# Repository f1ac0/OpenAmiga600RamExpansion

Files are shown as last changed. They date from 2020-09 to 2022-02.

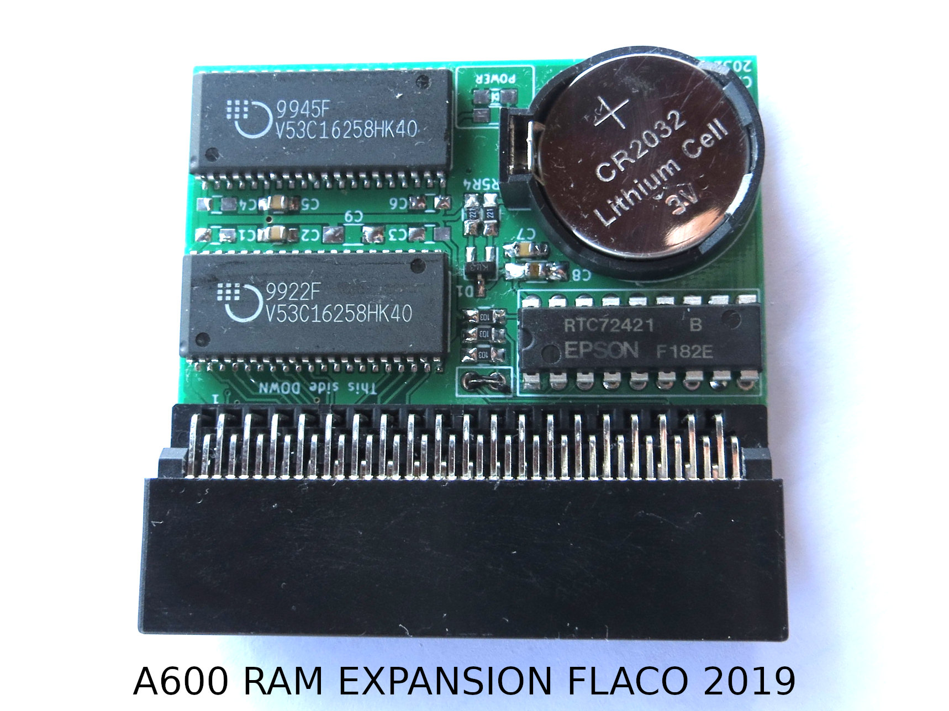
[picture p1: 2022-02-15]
OpenAmiga600RamExpansion FLACO 2019.JPG

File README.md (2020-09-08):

# OpenAmiga600RamExpansion
OpenAmiga600RamExpansion is an Open Hardware 1 MB Chip RAM Expansion for the Commodore Amiga 600 Computer with optional Real Time Clock, by SukkoPera https://github.com/SukkoPera/OpenAmiga600RamExpansion/.

This project is a different layout of the board, with almost the same BOM :
- smaller board, no space for ram chips sockets,
- inverted connector, so that components are facing downside and the solder joints do not touch the trapdoor,
- footprint for CR1220 in addition to the CR2032.

# Disclaimer
This is a hobbyist project, it comes with no warranty and no support.

This version is not connected to SukkoPera, please don't bother him with issues you might have because of it.

I publish this work using the same license as the original project : CERN OHL v1.2.

If you find it useful, please reward the original author. See the original repository.

# Making it
You should refer to the original repository where SukkoPera provides excellent advice about connector availability, RAM chips to use (I personally installed V53C16256HK40) and RTC. I confirm that AmigaTestKit is a must to check that the board is working fine (among other test).

Check for shorts at least between 5V and GND traces before applying power !

# Using it
- Install the battery,
- Plug to the motherboard,
- Power on the system.

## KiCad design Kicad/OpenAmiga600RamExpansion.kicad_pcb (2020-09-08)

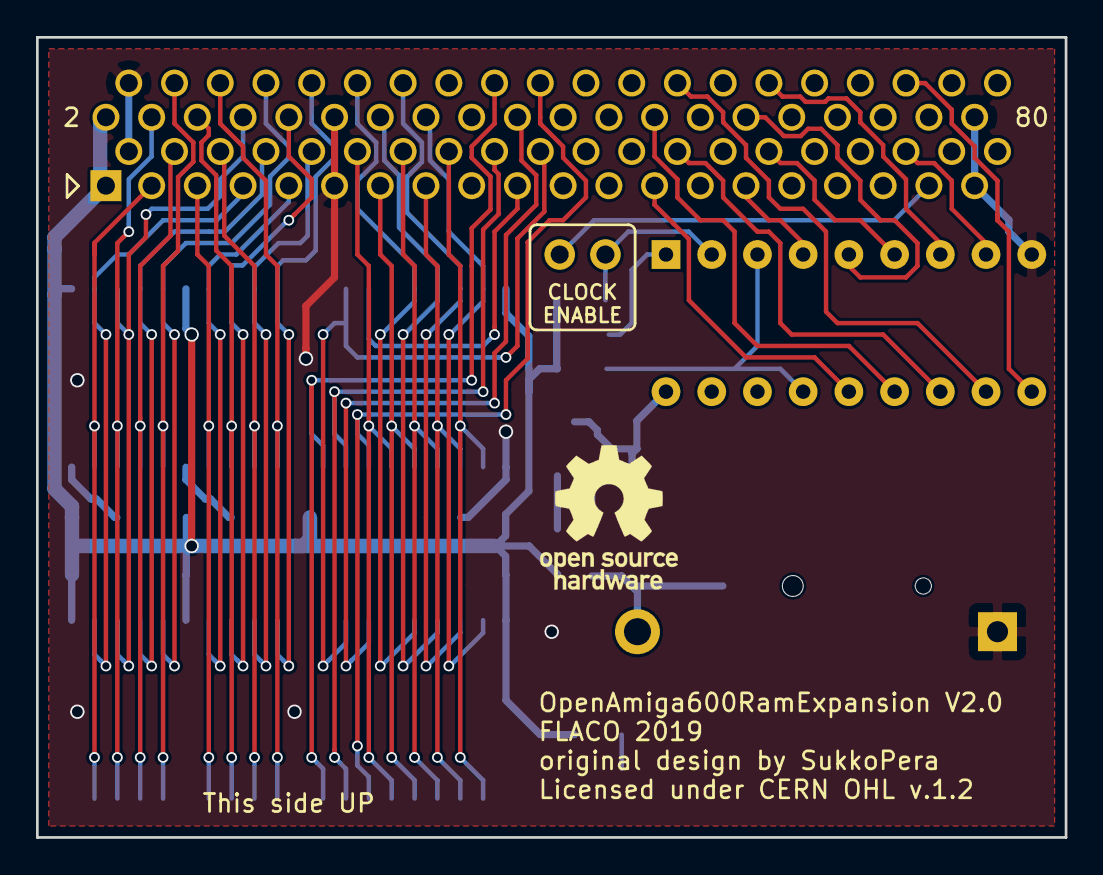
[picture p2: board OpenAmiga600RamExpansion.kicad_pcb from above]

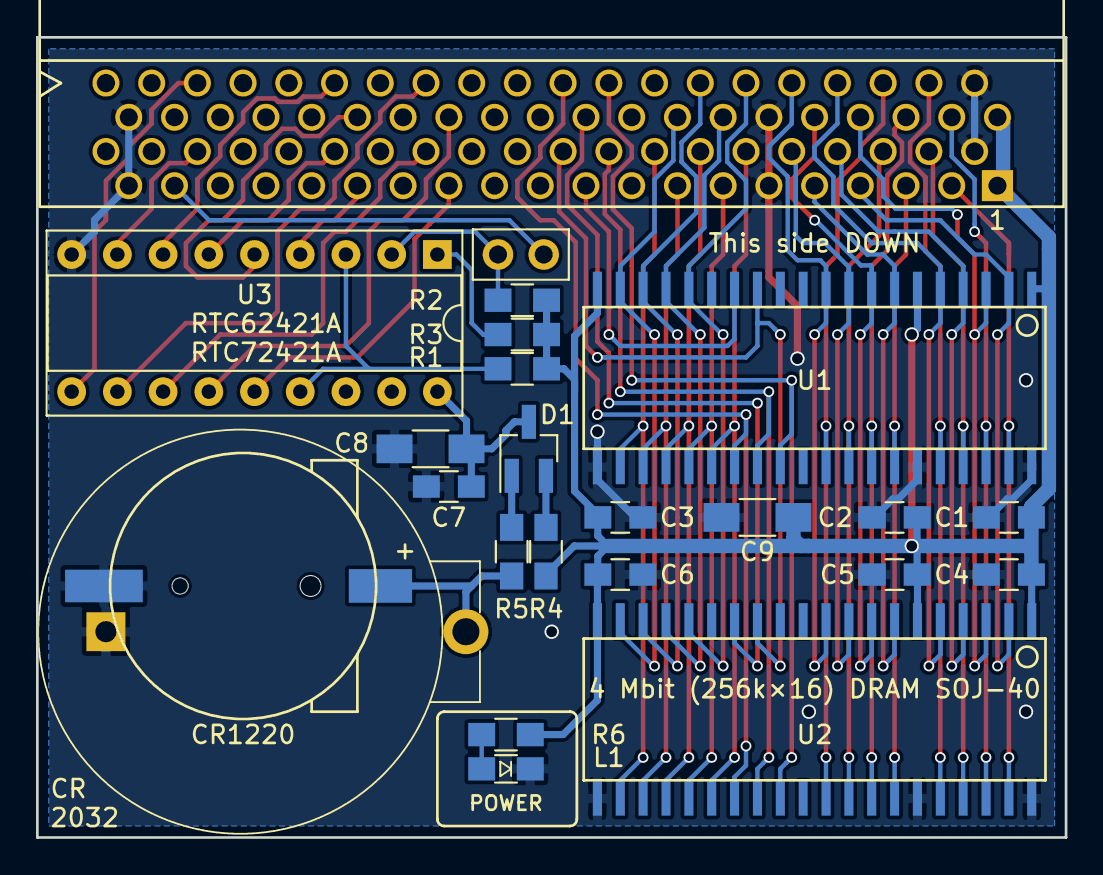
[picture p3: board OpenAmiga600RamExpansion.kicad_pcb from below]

Board: 2 copper layers, 57.2 x 44.4 mm, 25 parts (24 on the bottom side), 52 nets.

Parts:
BT1: CR2032; Battery_Holder_Coin_2032_BS-7
BT2: CR1220; Battery_Holder_Coin_1220_BS-1220-1
C1, C2, C3, C4, C5, C6, C7: 100n; C_0805_HandSoldering
C8: 2.2uF; C_1206_HandSoldering
C9: 10uF; C_1206_HandSoldering
CONN1: A600_TRAPDOOR; 4UCON_10156_90deg_A600
D1: BAT54C; SOT-23_Handsoldering
J1: Conn_01x02; Pin_Header_Straight_1x02-ModSilkS
J99: OSHW_LOGO; OSHW-Logo_7.5x8mm_SilkScreen
L1: LED; LED_0805_HandSoldering_ModSilkS
R1, R2, R3: 10k; R_0805_HandSoldering
R4, R5: 220; R_0805_HandSoldering
R6: 1K; R_0805_HandSoldering
U1, U2: NEC_424260; SOJ-40-longpads
U3: MSM6242B; DIP-18_W7.62mm_Socket

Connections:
/CASL1: CONN1.35, U1.28, U2.28
/CASU1: CONN1.36, U1.29, U2.29
/OE: CONN1.40, U1.27, U2.27
/RAS0: CONN1.37, U1.14
/RAS1: CONN1.38, U2.14
/WE: CONN1.39, U1.13, U2.13
/a0: CONN1.24, U1.16, U2.16
/a1: CONN1.26, U1.17, U2.17
/a2: CONN1.28, U1.18, U2.18
/a3: CONN1.30, U1.19, U2.19
/a4: CONN1.31, U1.22, U2.22
/a5: CONN1.29, U1.23, U2.23
/a6: CONN1.27, U1.24, U2.24
/a7: CONN1.25, U1.25, U2.25
/a8: CONN1.23, U1.26, U2.26
/d0: CONN1.13, U1.2, U2.2
/d1: CONN1.14, U1.3, U2.3
/d2: CONN1.15, U1.4, U2.4
/d3: CONN1.16, U1.5, U2.5
/d4: CONN1.17, U1.7, U2.7
/d5: CONN1.18, U1.8, U2.8
/d6: CONN1.19, U1.9, U2.9
/d7: CONN1.20, U1.10, U2.10
/d8: CONN1.12, U1.31, U2.31
/d9: CONN1.11, U1.32, U2.32
/d10: CONN1.10, U1.33, U2.33
/d11: CONN1.9, U1.34, U2.34
/d12: CONN1.8, U1.36, U2.36
/d13: CONN1.7, U1.37, U2.37
/d14: CONN1.6, U1.38, U2.38
/d15: CONN1.5, U1.39, U2.39
/rtc_a0: CONN1.57, U3.4
/rtc_a1: CONN1.58, U3.5
/rtc_a2: CONN1.59, U3.6
/rtc_a3: CONN1.60, U3.7
/rtc_cs: CONN1.73, J1.2
/rtc_d0: CONN1.49, U3.14
/rtc_d1: CONN1.50, U3.13
/rtc_d2: CONN1.51, U3.12
/rtc_d3: CONN1.52, U3.11
/rtc_rd: CONN1.71, U3.8
/rtc_wr: CONN1.72, U3.10
GND: BT1.2, BT2.2, C1.2, C2.2, C3.2, C4.2, C5.2, C6.2, C7.2, C8.2, C9.2, CONN1.3, CONN1.4, CONN1.21, CONN1.22, CONN1.77, CONN1.78, L1.1, U1.21, U1.35, U1.40, U2.21, U2.35, U2.40, U3.9
unnamed: BT1.1, BT2.1, R5.1
unnamed: D1.1, R5.2
unnamed: D1.2, R4.2
unnamed: J1.1, R2.2, U3.2
unnamed: L1.2, R6.1
unnamed: R1.2, U3.3, U3.15
unnamed: R3.2, U3.1
VCC: C1.1, C2.1, C3.1, C4.1, C5.1, C6.1, C9.1, CONN1.1, CONN1.2, R1.1, R2.1, R3.1, R4.1, R6.2, U1.1, U1.6, U1.20, U2.1, U2.6, U2.20
VDD: C7.1, C8.1, D1.3, U3.18

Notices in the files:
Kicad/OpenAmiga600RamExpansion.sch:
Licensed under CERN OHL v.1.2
